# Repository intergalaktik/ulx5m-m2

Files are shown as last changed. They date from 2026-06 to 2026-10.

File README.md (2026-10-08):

# Work in progress!!! 

# Please check the list of confirmed working

# ULX5M-GS
GateMate FPGA on M2 card

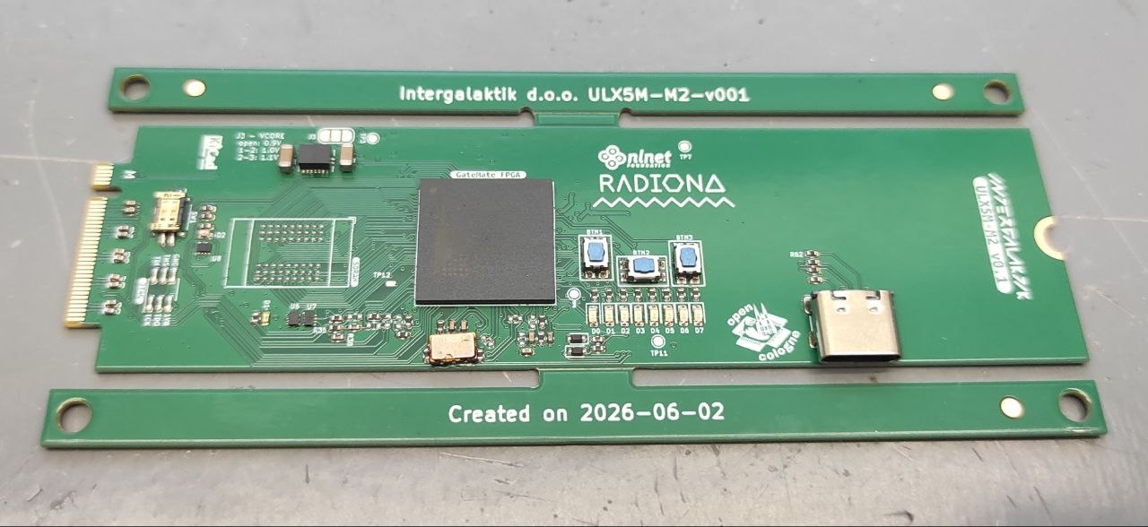
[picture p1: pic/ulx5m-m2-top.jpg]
TOP

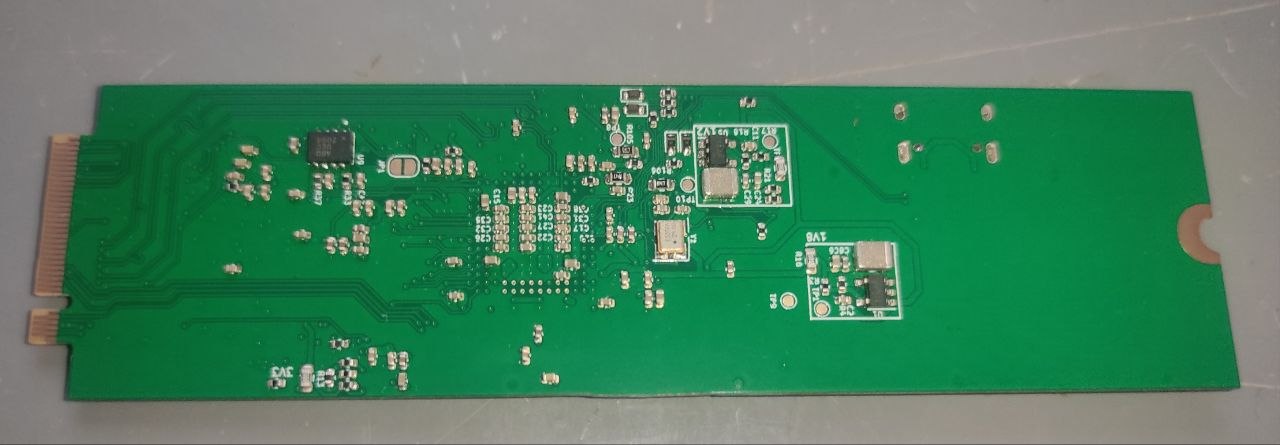
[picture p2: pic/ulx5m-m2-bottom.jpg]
BOTTOM


## Blinky

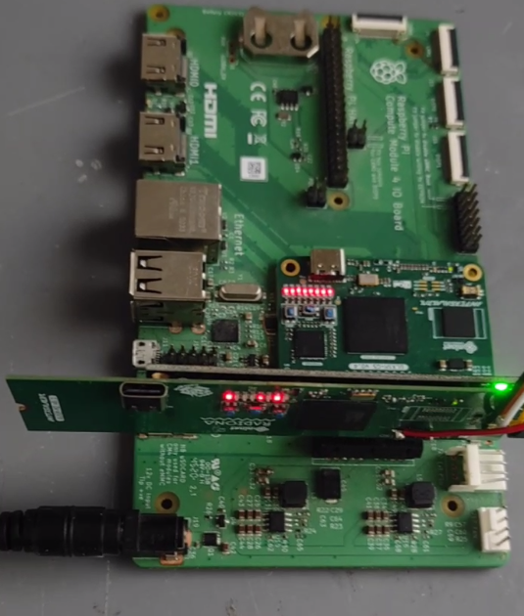
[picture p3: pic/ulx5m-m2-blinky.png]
Blinky video


#### ULX5M-M2 V001

- [x] JTAG 
- [x] FLASH
- [x] LEDs
- [x] Blinkey
- [x] USB - device shows up
- [] BTNS
- [] SDRAM
- [x] SerDes with connection to ULX5M-GS - low speed 1.25Gbit/s SerDes transfer.
- [] PCIe

#### ULX5M-M2 V002 - ready for order

- [] JTAG 
- [] FLASH
- [] LEDs
- [] Blinkey
- [] USB - device shows up
- [] BTNS
- [] SDRAM
- [] SerDes with connection to ULX5M-GS I am getting low speed SerDes transfer.
- [] PCIe

## References

https://github.com/intergalaktik/ulx5m-gs

https://github.com/OLIMEX/GateMateA1-EVB

https://github.com/intergalaktik/Extension_Boards_for_Olimex_GateMate

https://github.com/YosysHQ/prjpeppercorn-test-cases

https://github.com/YosysHQ/prjpeppercorn
  
https://github.com/chili-chips-ba/openCologne

https://www.chili-chips.xyz/open-cologne

## Acknowledgements

This project was done in collaboration with Chili Chips*Ba team. 
They have put enormes effort in making all cores to work on GateMate even before we have our own board!
Thanks to them now we have big set of cores that can be used to check and improve opensource toolchain!
They are proven to be reliable partners that solves problem quickly and on side works on educating younger generations!
Also big thanks goes to YosysHQ as they are doing miracles with open source tooling, and we now finaly have one that works for GateMate!
From YosysHQ special thanks to Micko and Lofty that are helping in real time on Discord!
Special thanks to Patrick from Cologne, as without him and rest of Cologne team we would not be able to get this project done.

## Work on this board is financed by NLnet foundation

NLnet

https://nlnet.nl/project/openCologne/

https://nlnet.nl/project/OpenCologne-PCIe/

https://github.com/chili-chips-ba/openCologne-PCIE

This project was funded through the NGI0 Commons Fund, a fund established by NLnet with financial support from the European Commission's Next Generation Internet programme, under the aegis of DG Communications Networks, Content and Technology under grant agreement No 101135429. Additional funding is made available by the Swiss State Secretariat for Education, Research and Innovation (SERI).

## Check up our blogposts
Comming soon!!!

## Contact us

Discord: https://discord.gg/qwMUk6W

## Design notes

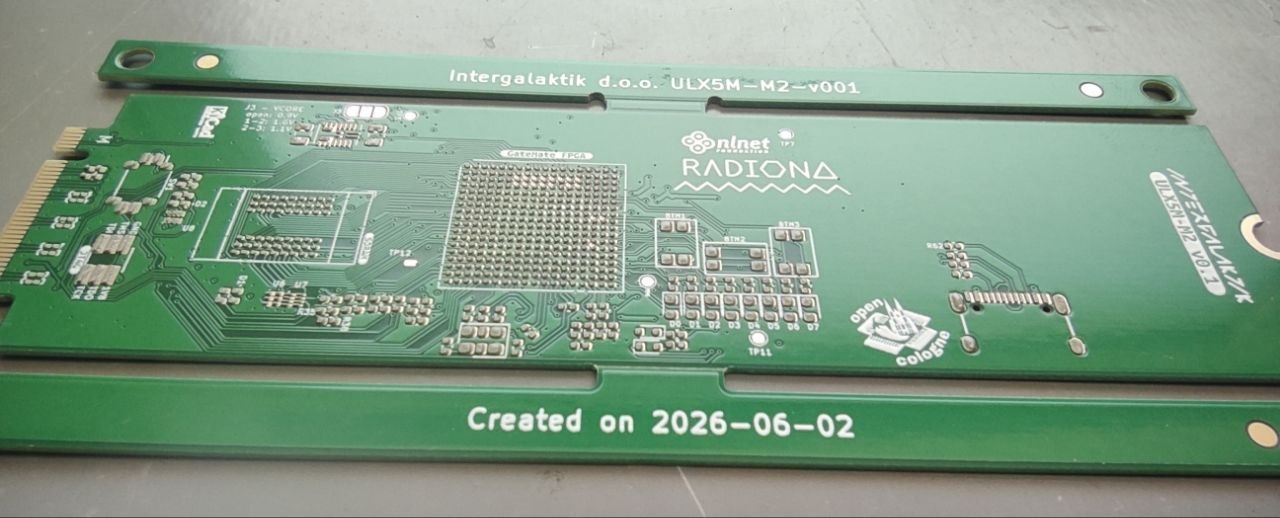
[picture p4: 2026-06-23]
pic/ulx5m-m2-top-paste.jpg

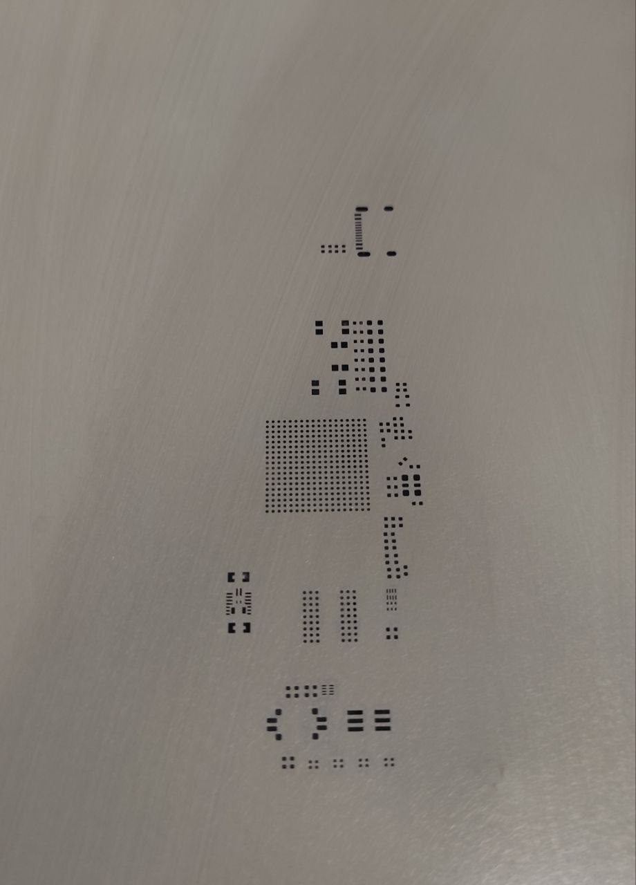
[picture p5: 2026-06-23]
pic/ulx5m-m2-top-stencill.jpg

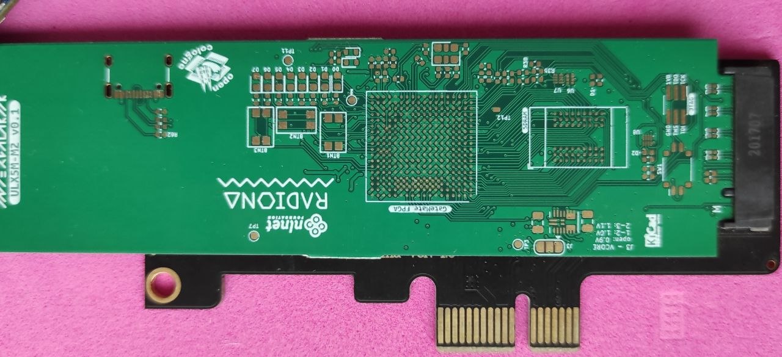
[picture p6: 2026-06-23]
pic/ulx5m-m2-top-PCIe.jpg

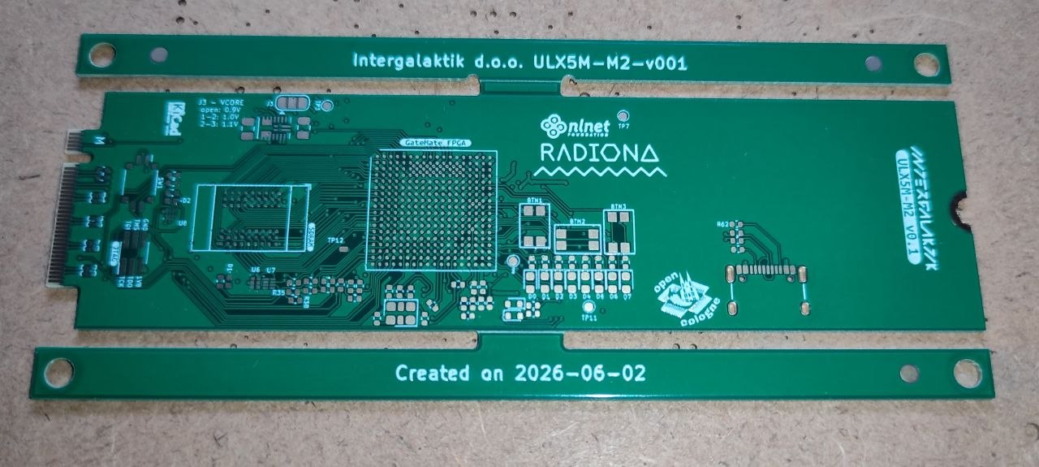
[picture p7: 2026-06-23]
pic/ulx5m-m2-top-PCB.jpg

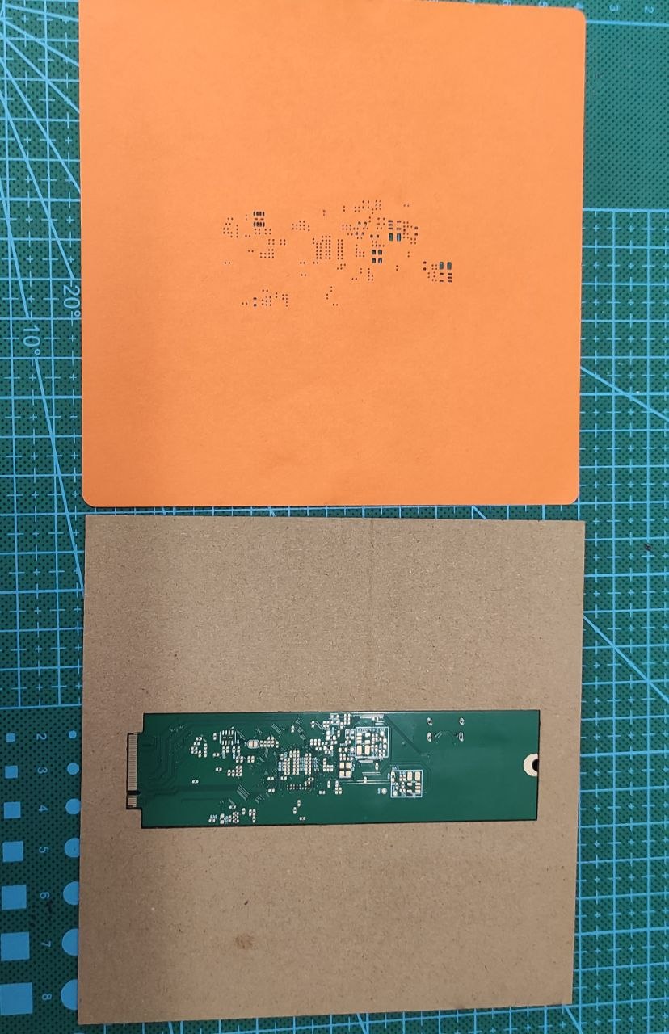
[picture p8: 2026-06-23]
pic/ulx5m-m2-bottom-stencill.jpg

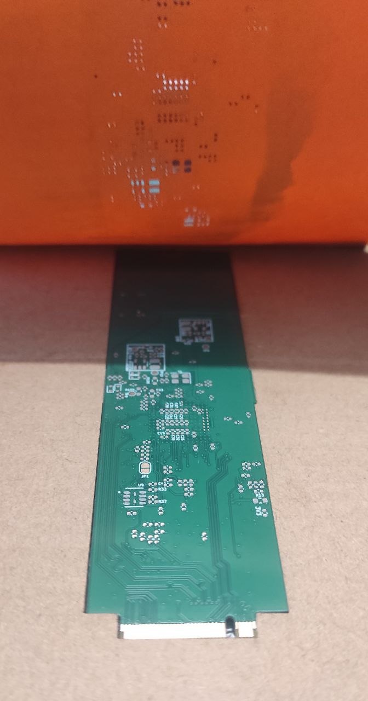
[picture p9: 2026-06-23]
pic/ulx5m-m2-bottom-stencill-paste.jpg

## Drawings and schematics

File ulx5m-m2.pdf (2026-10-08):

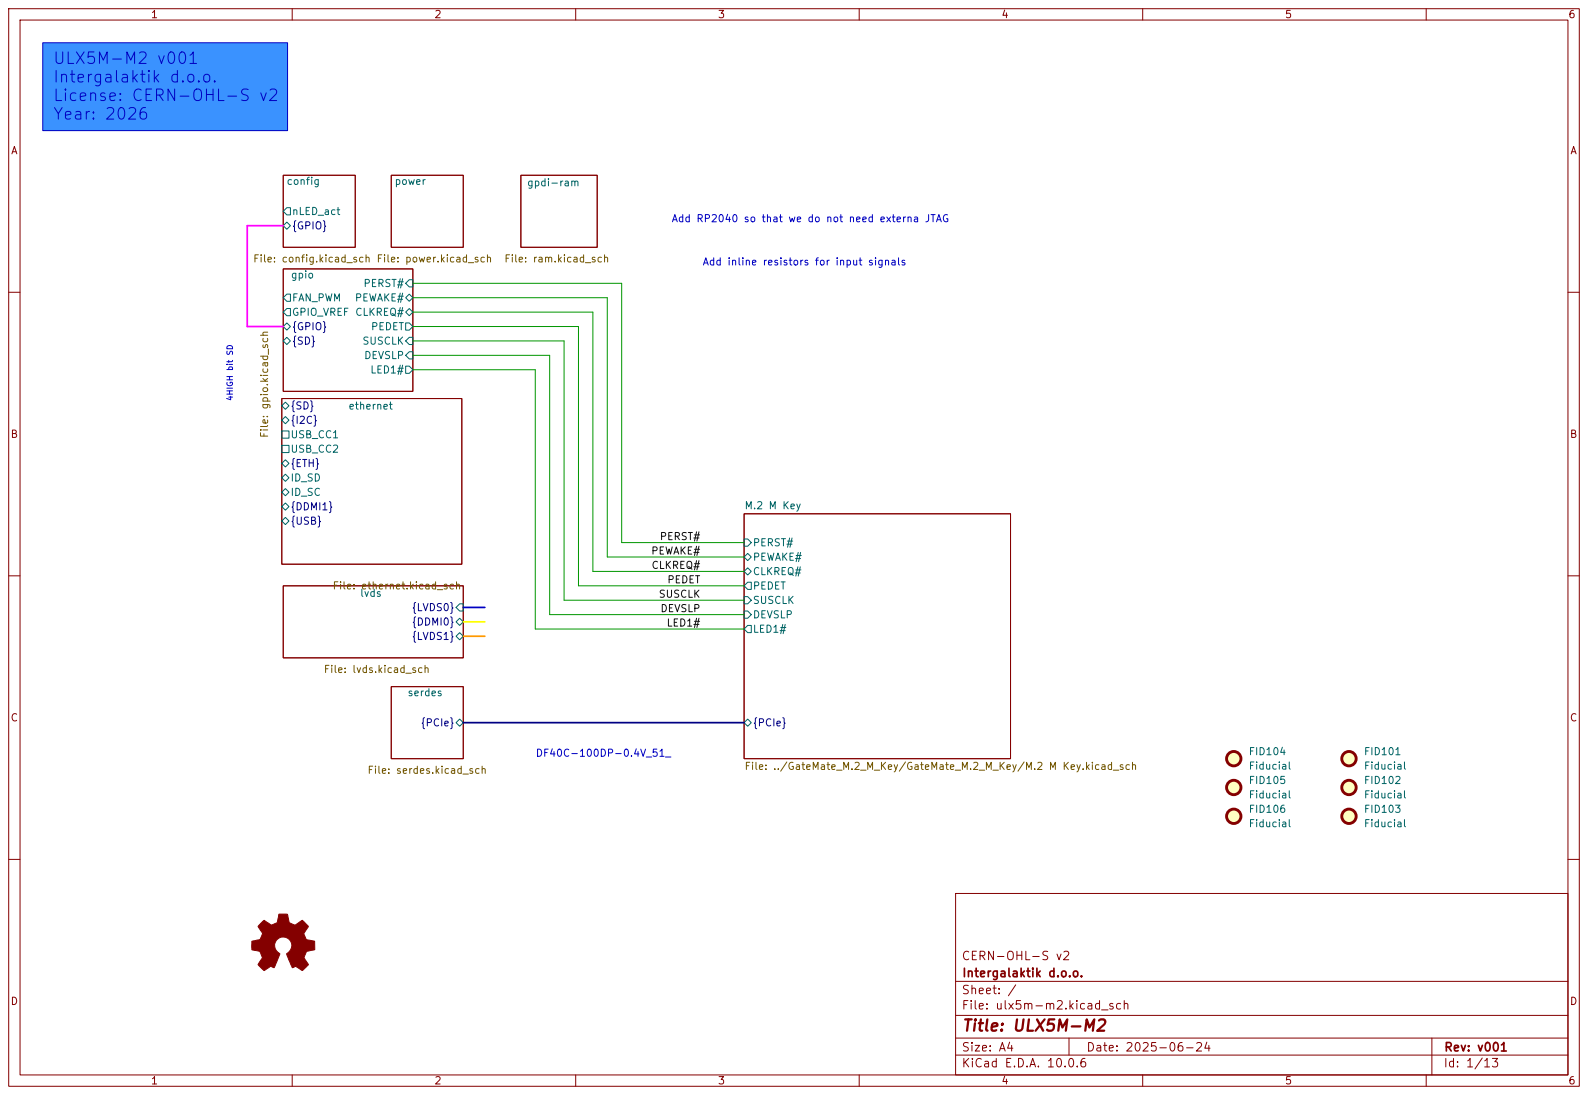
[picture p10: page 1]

Add RP2040 so that we do not need externa JTAG Add inline resistors for input signals 4HIGH bit SD

{PCIe} M.2 M Key File: ../GateMate_M.2_M_Key/GateMate_M.2_M_Key/M.2 M Key.kicad_sch

{PCIe} serdes File: serdes.kicad_sch

Size: A4 | Rev: v001
KiCad E.D.A. 10.0.6 | Id: 1/13

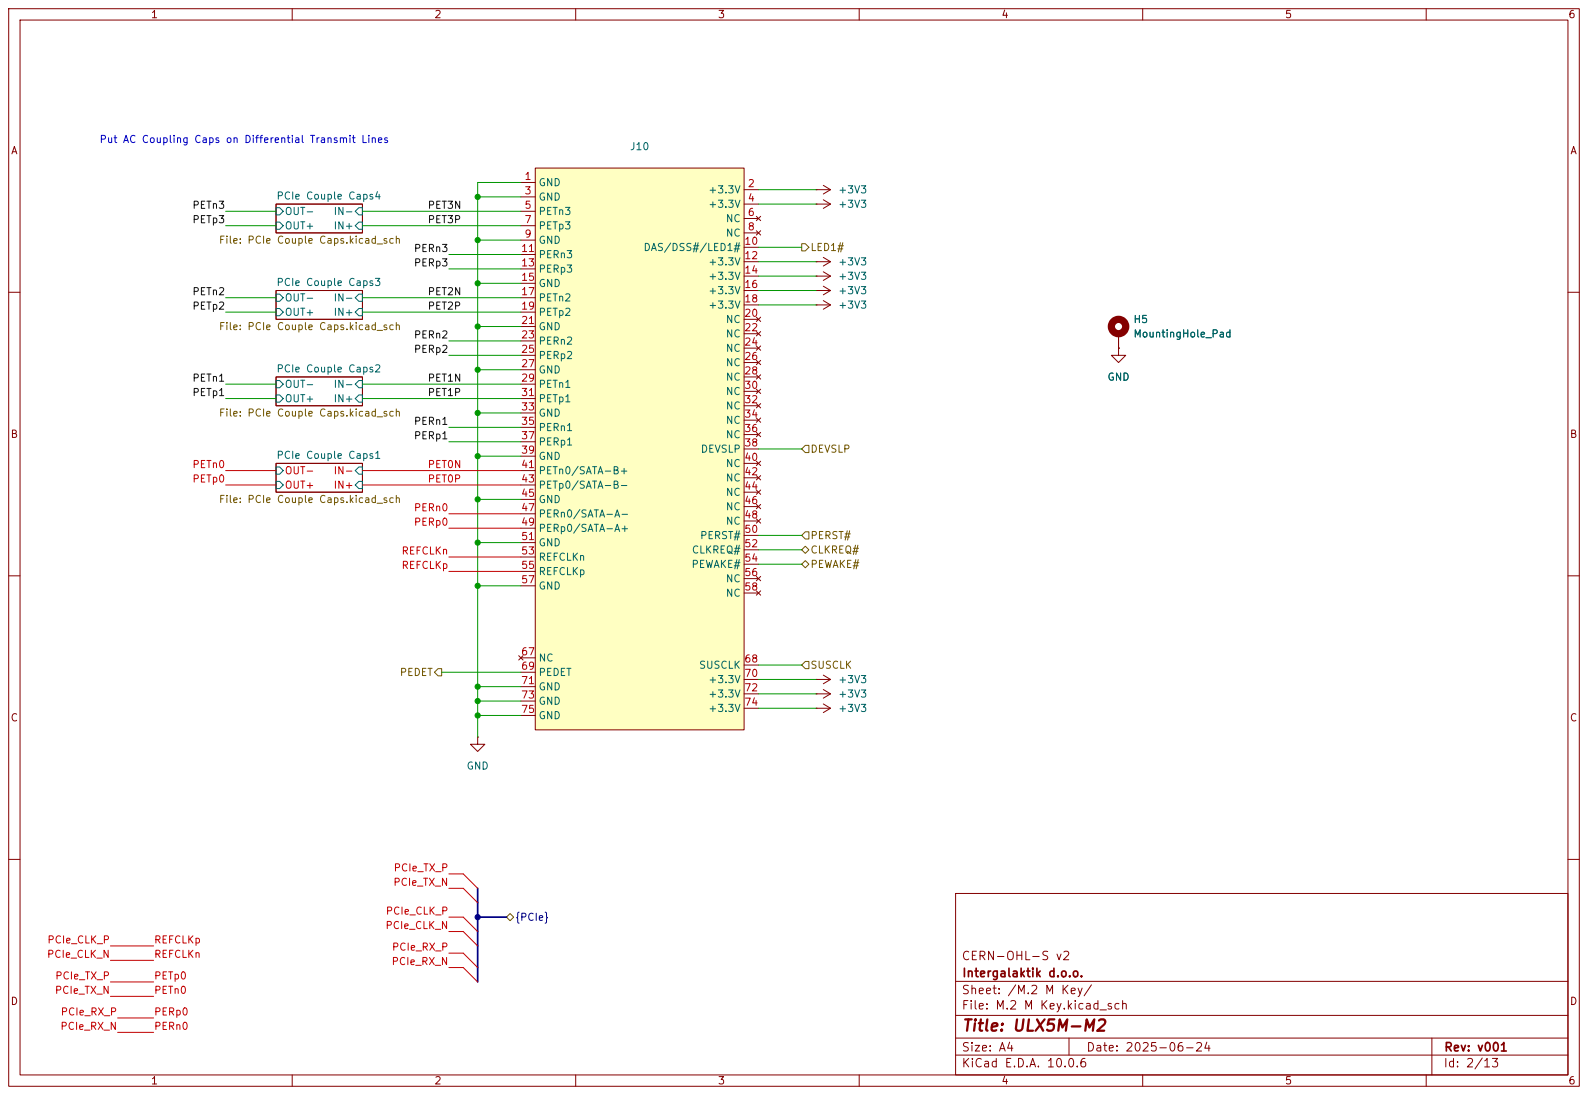
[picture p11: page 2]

File: PCIe Couple Caps.kicad_sch OUT-

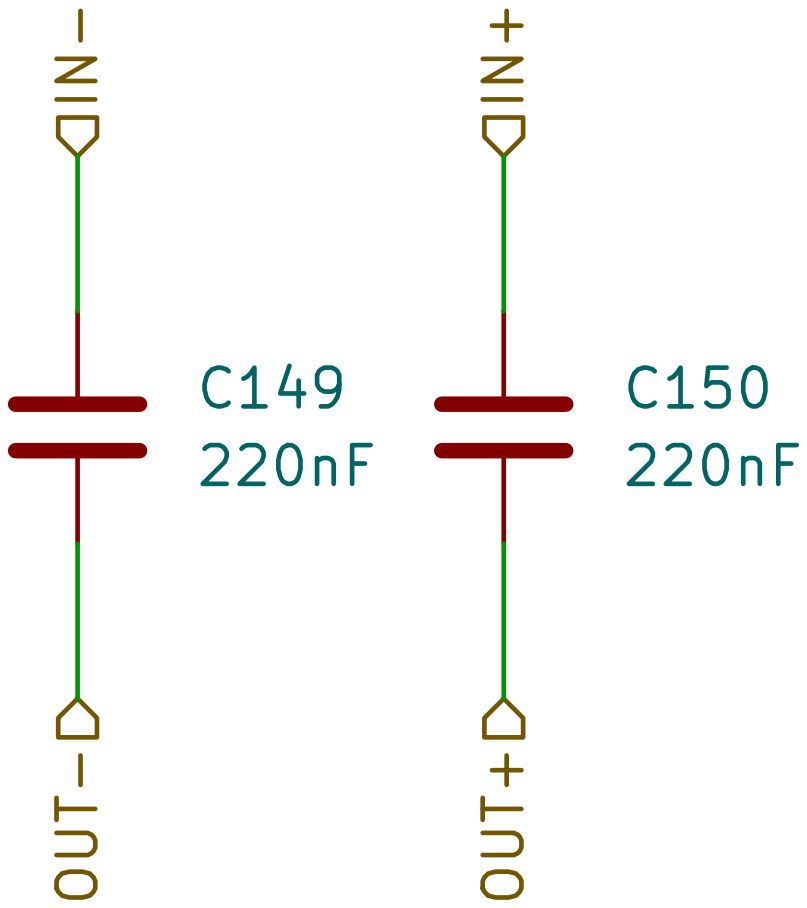
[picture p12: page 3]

CERN-OHL-S v2
Intergalaktik d.o.o.
Sheet: /M.2 M Key/PCIe Couple Caps4/
File: PCIe Couple Caps.kicad_sch
Title: ULX5M-M2

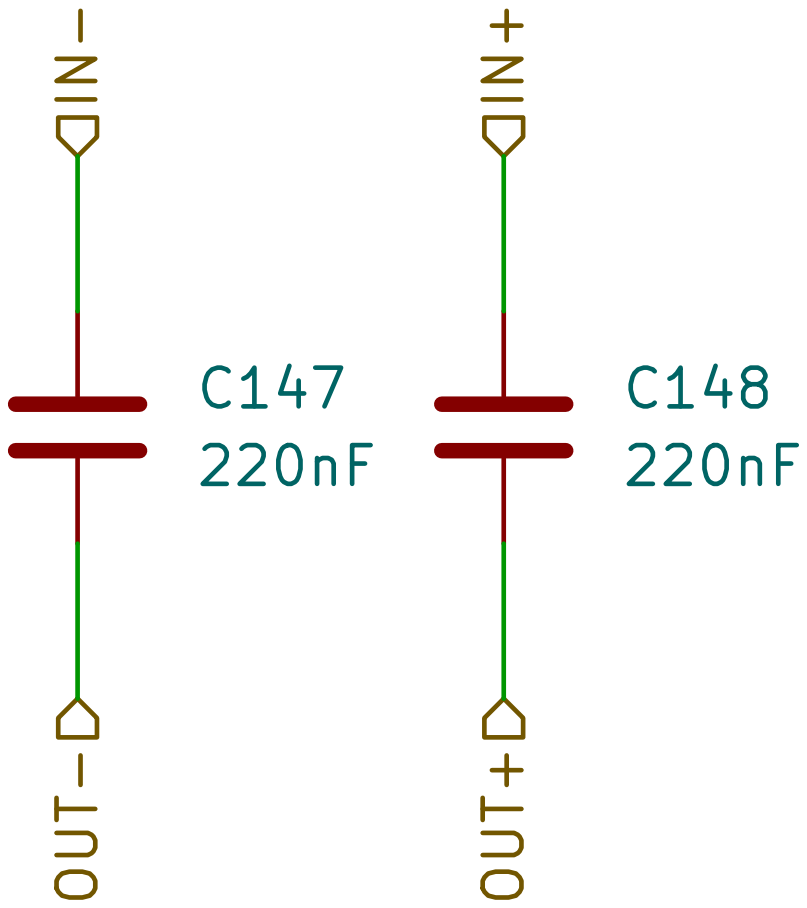
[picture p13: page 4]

CERN-OHL-S v2
Intergalaktik d.o.o.
Sheet: /M.2 M Key/PCIe Couple Caps3/
File: PCIe Couple Caps.kicad_sch
Title: ULX5M-M2

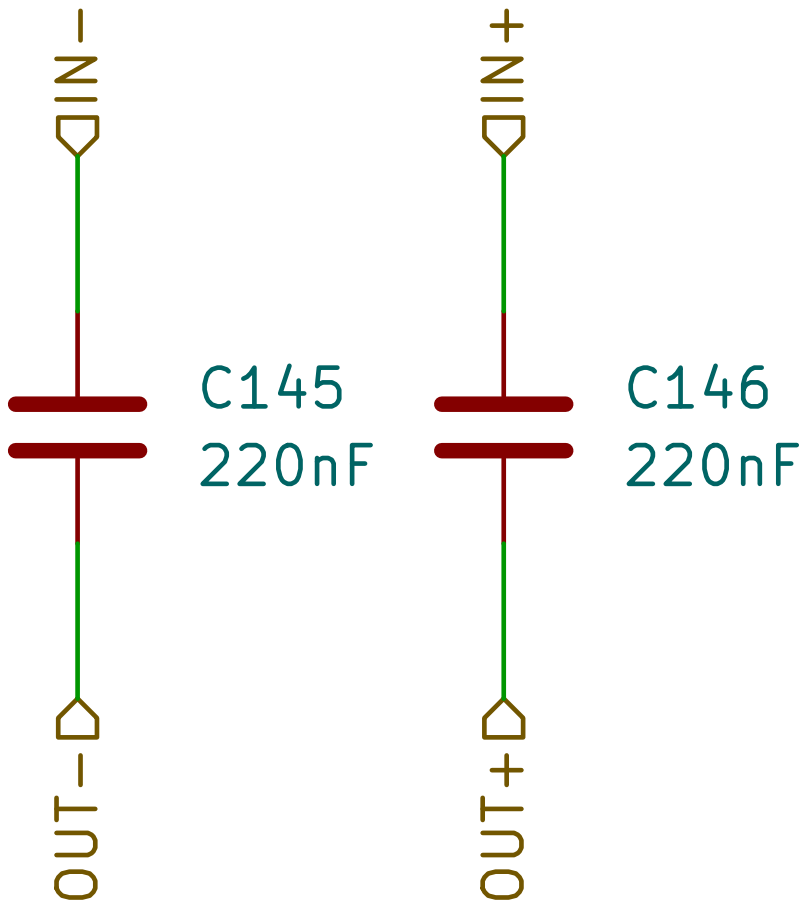
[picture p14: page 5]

CERN-OHL-S v2
Intergalaktik d.o.o.
Sheet: /M.2 M Key/PCIe Couple Caps2/
File: PCIe Couple Caps.kicad_sch
Title: ULX5M-M2

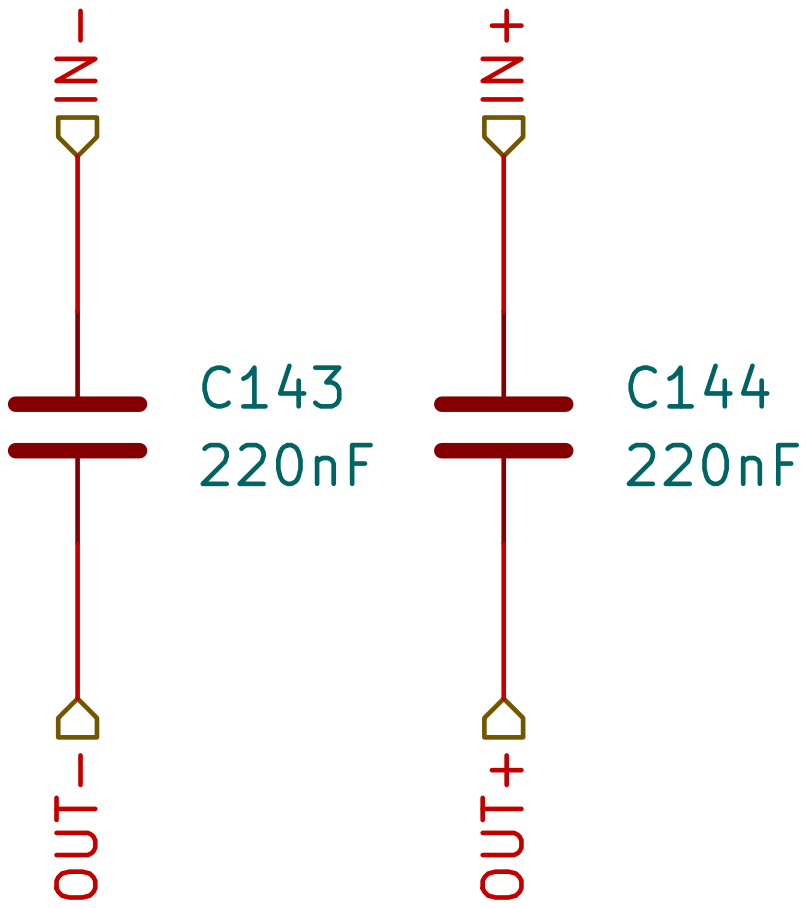
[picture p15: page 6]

CERN-OHL-S v2
Intergalaktik d.o.o.
Sheet: /M.2 M Key/PCIe Couple Caps1/
File: PCIe Couple Caps.kicad_sch
Title: ULX5M-M2

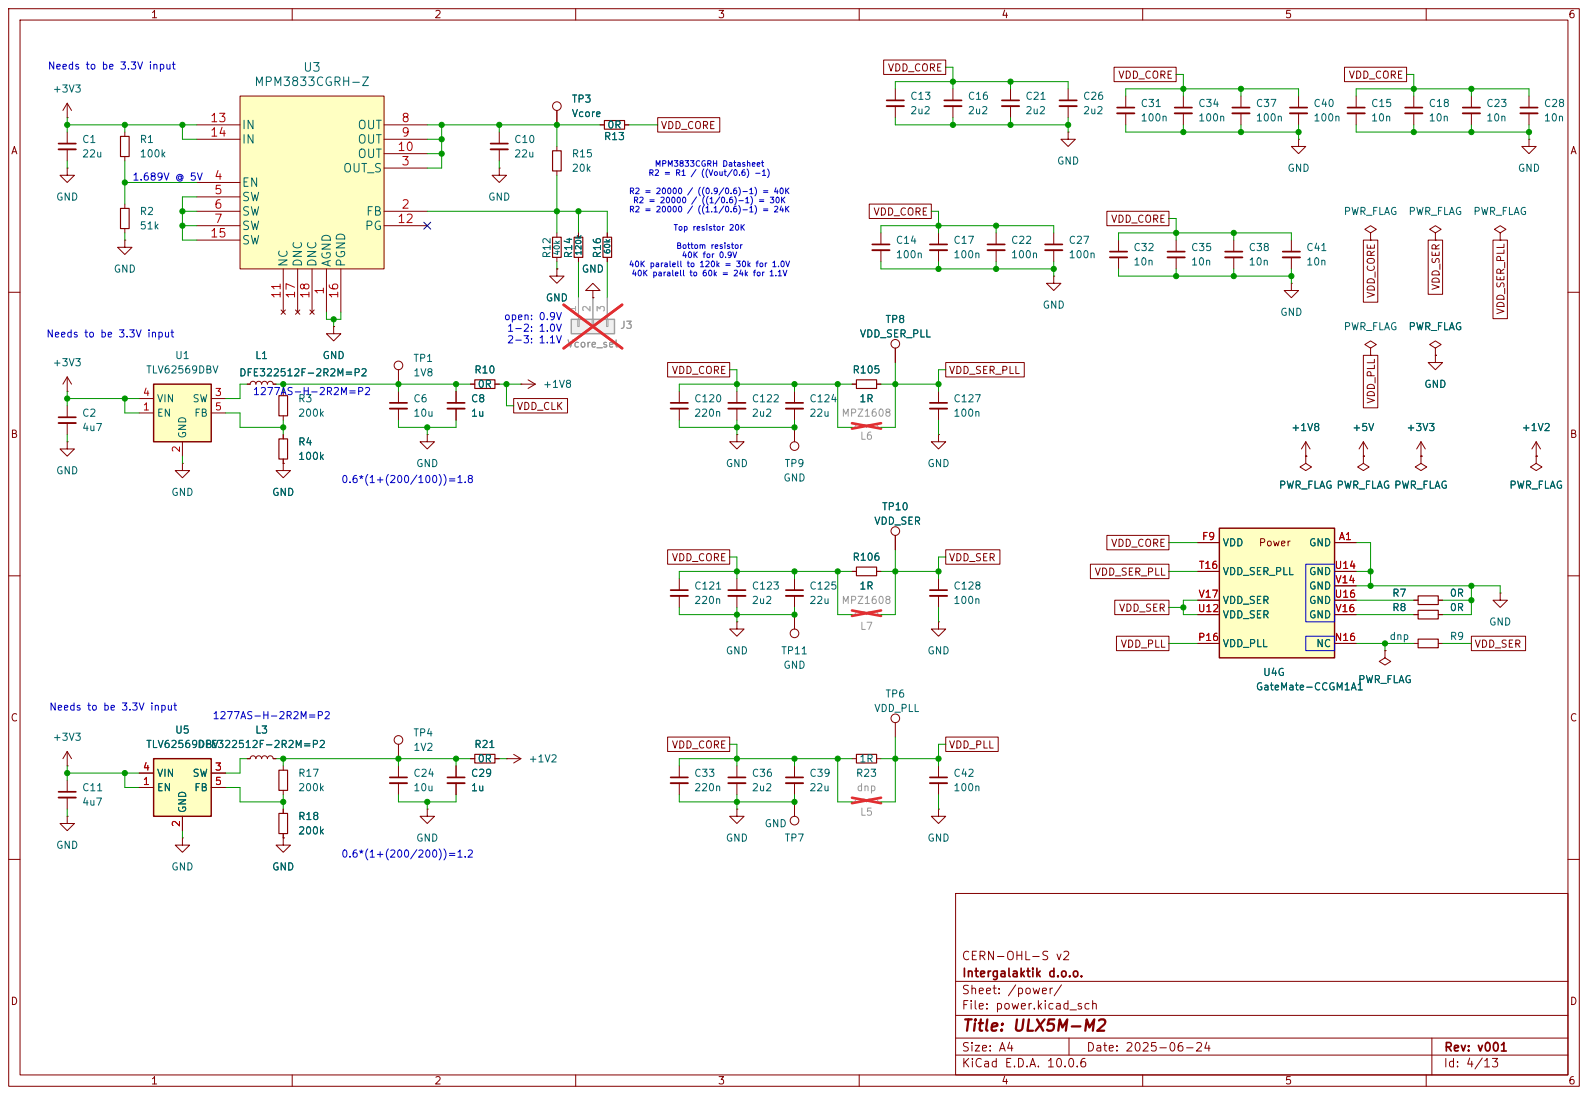
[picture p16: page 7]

Bottom resistor 40K for 0.9V 40K paralell to 120k = 30k for 1.0V 40K paralell to 60k = 24k for 1.1V 1277AS-H-2R2M=P2

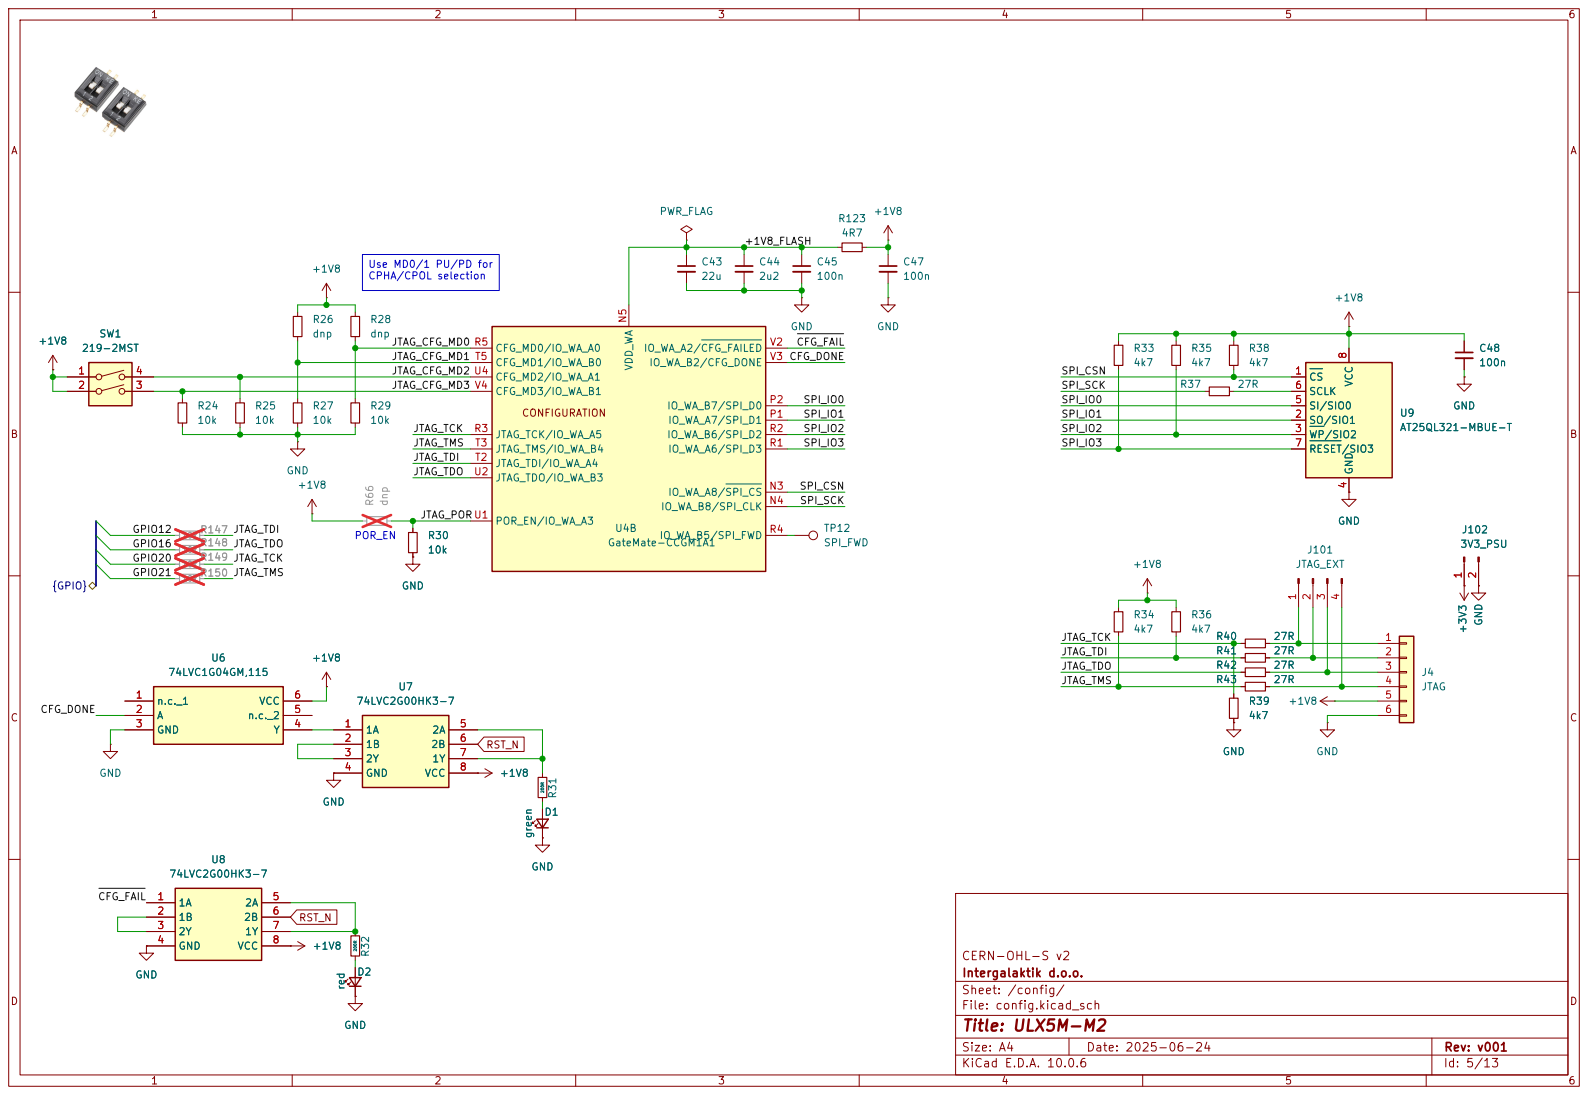
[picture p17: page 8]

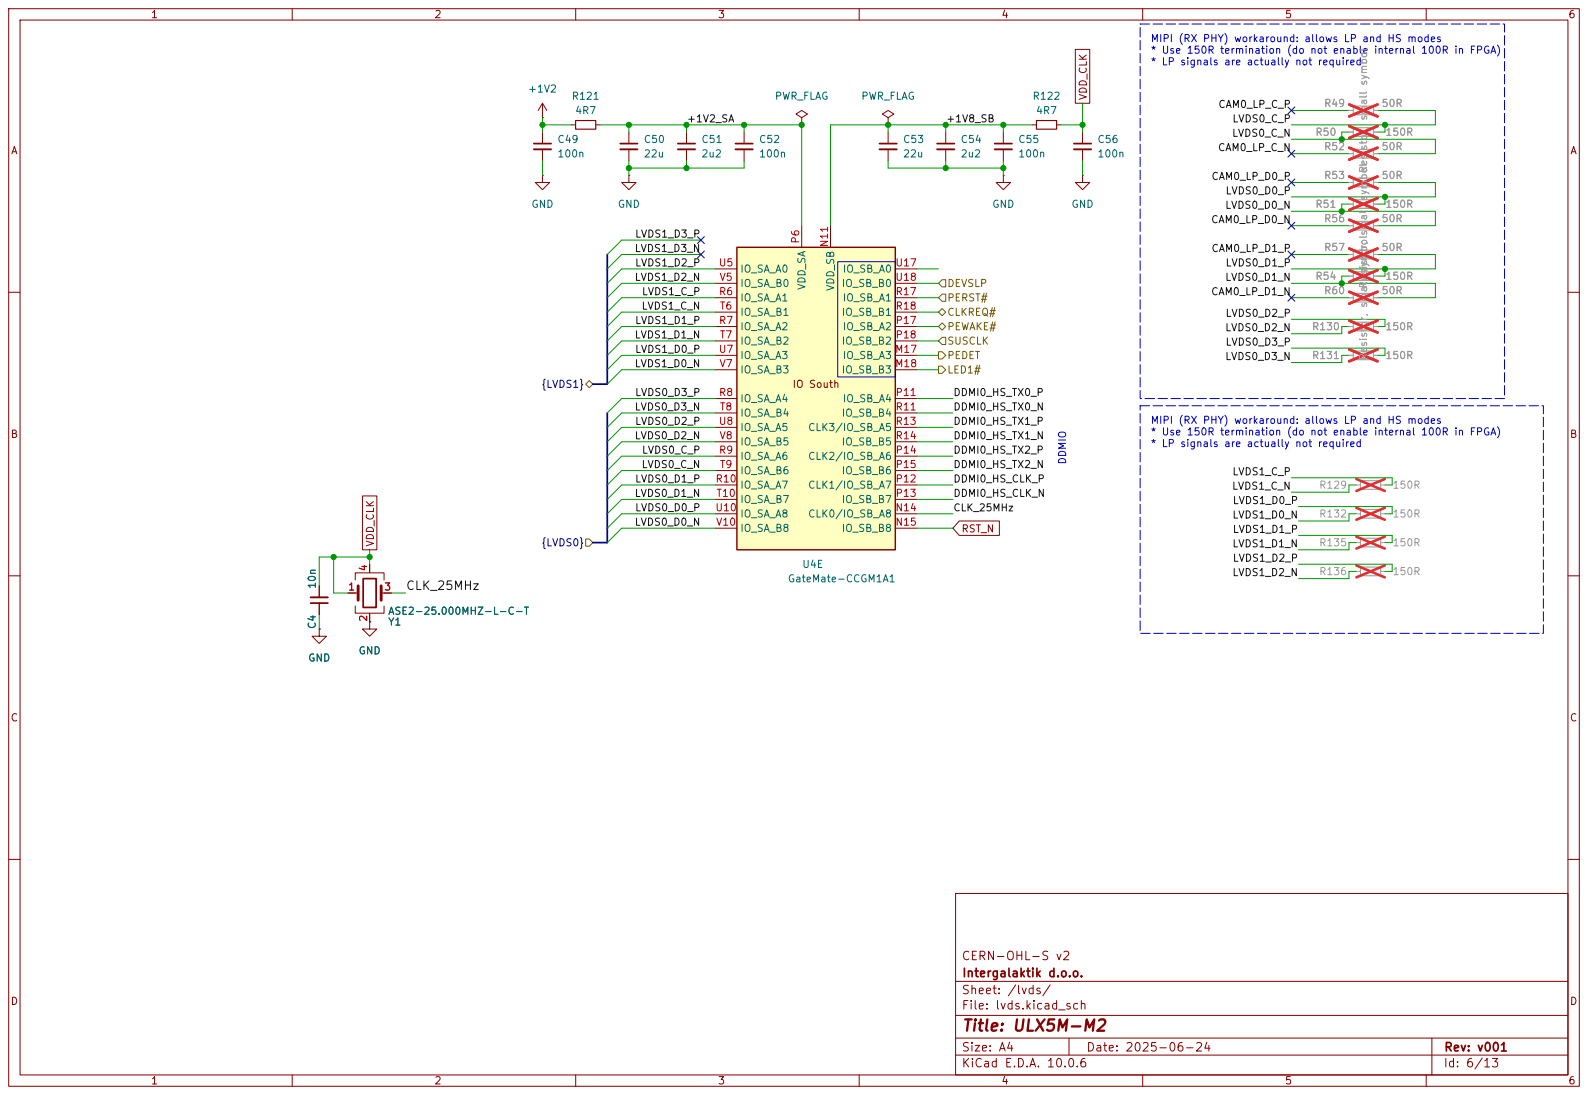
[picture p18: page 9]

* Use 150R termination (do not enable internal 100R in FPGA) * LP signals are actually not required

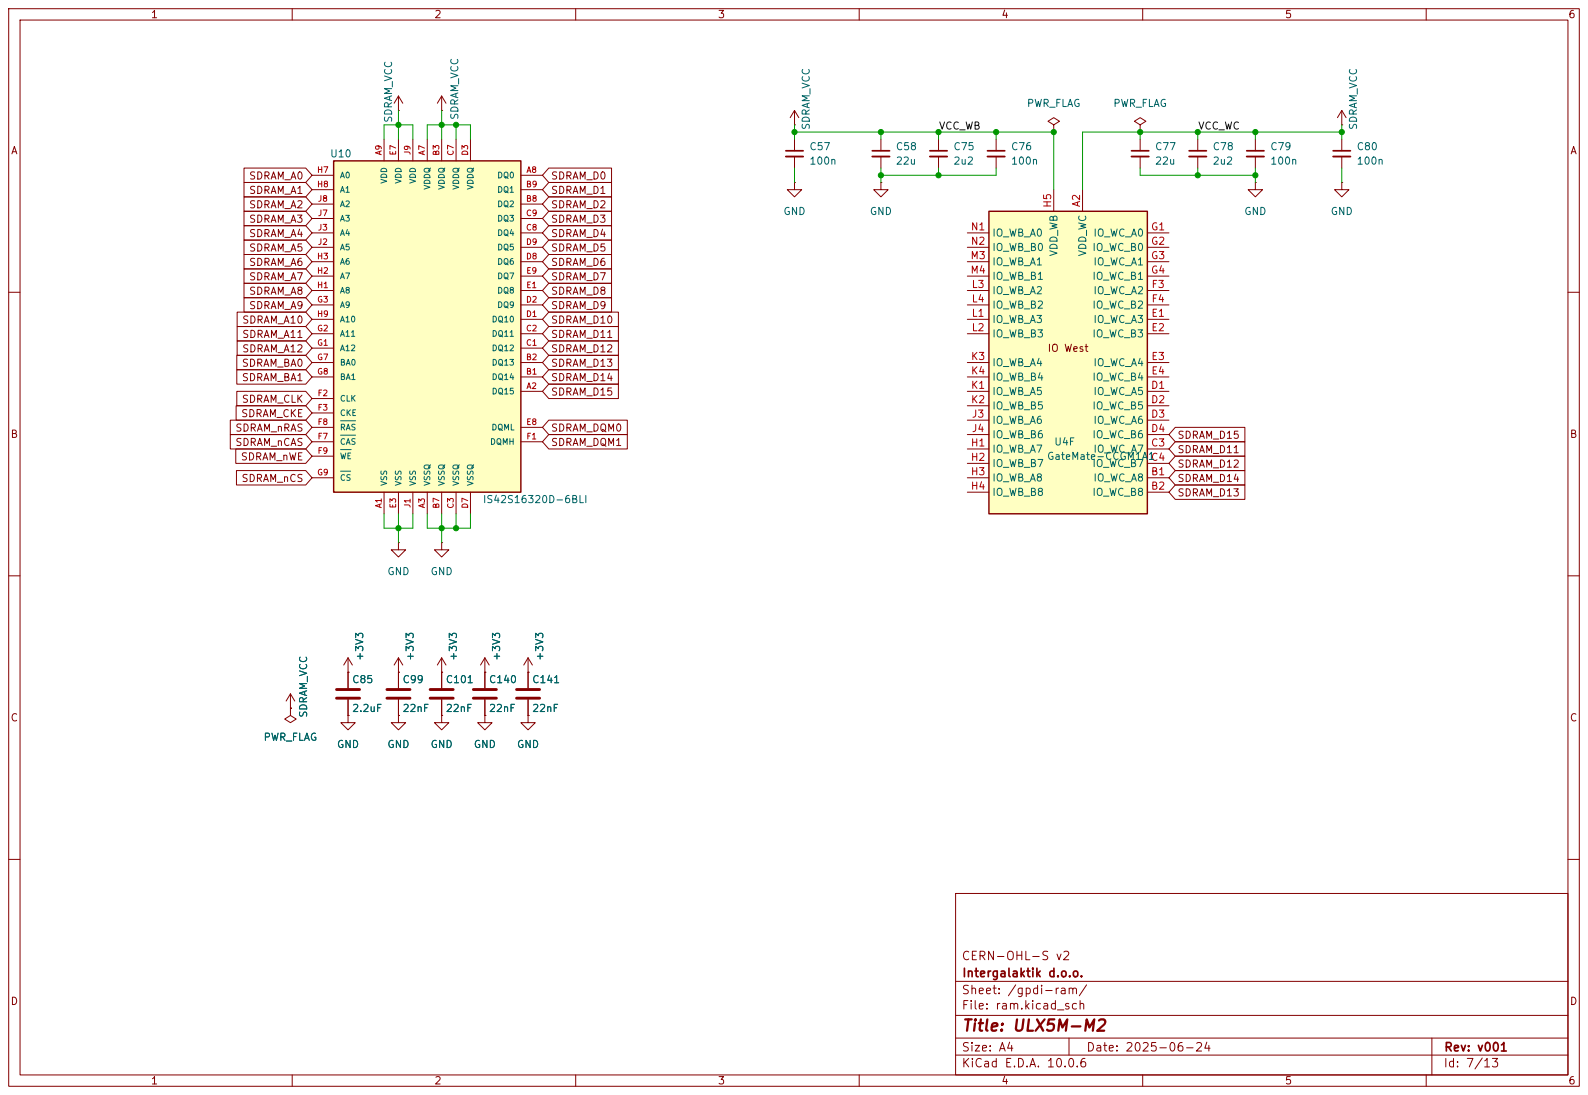
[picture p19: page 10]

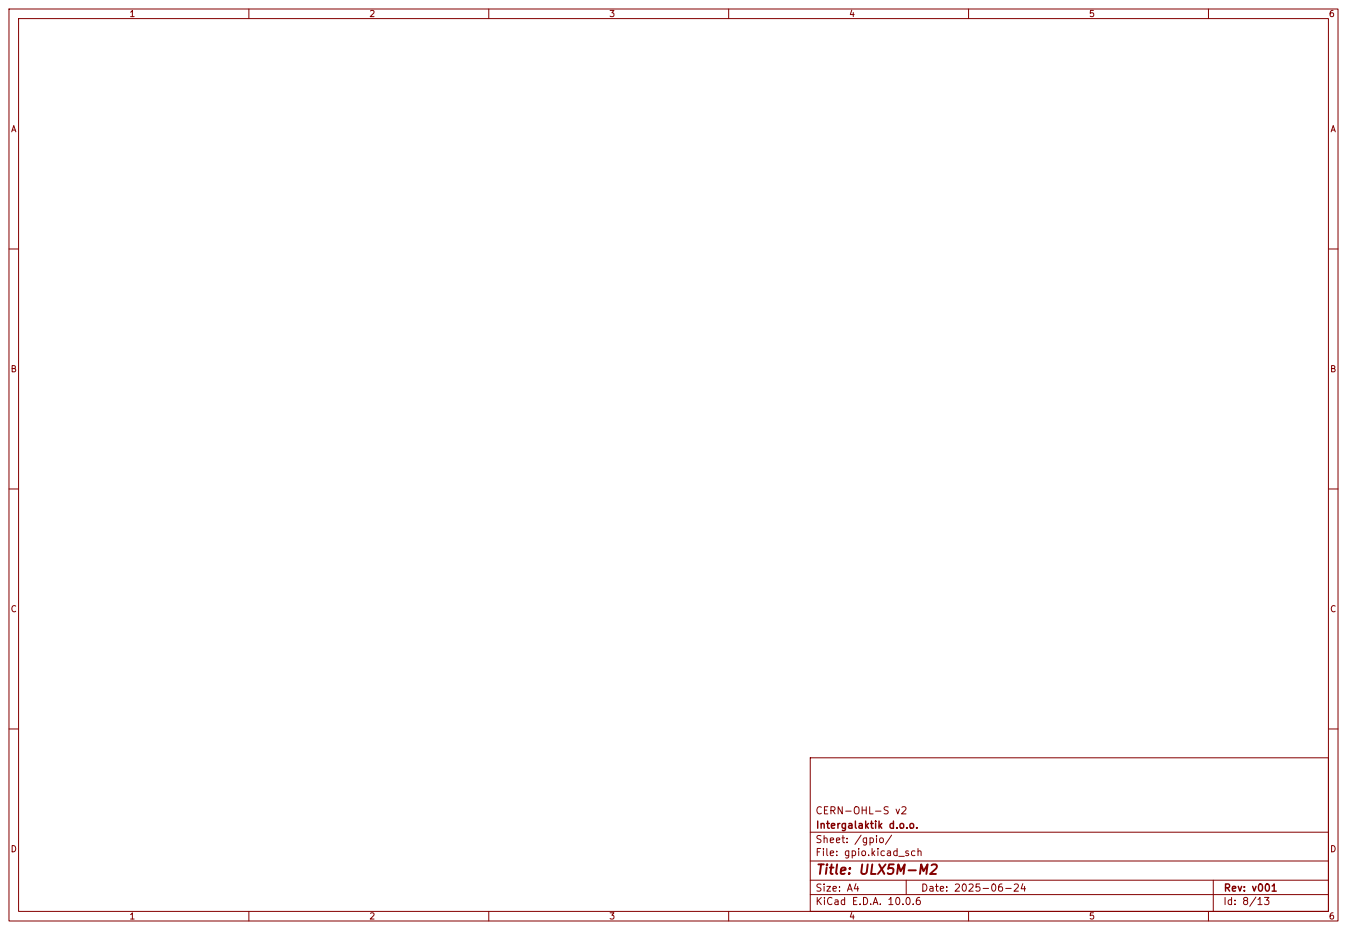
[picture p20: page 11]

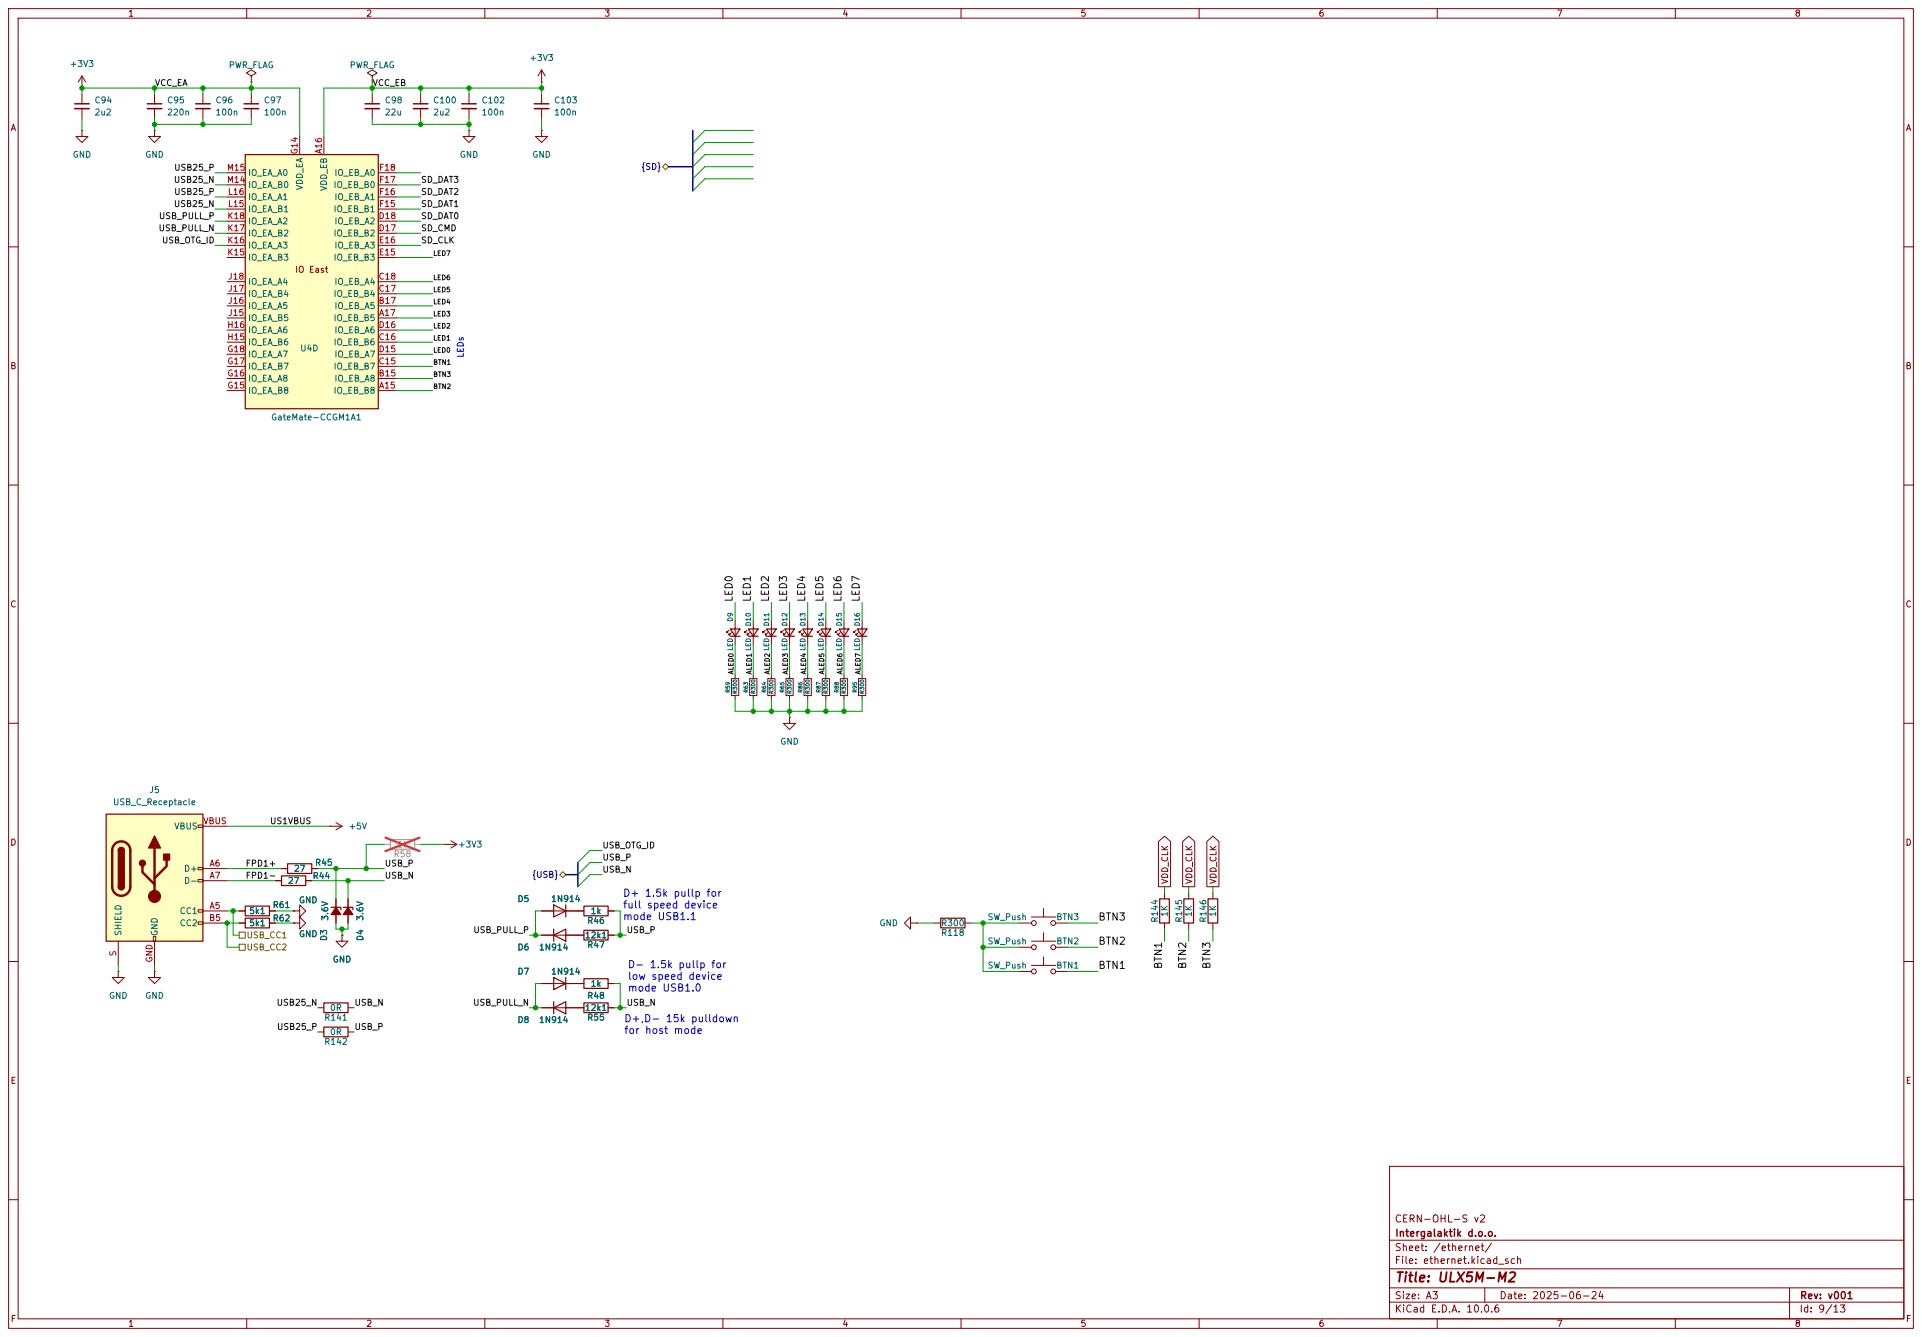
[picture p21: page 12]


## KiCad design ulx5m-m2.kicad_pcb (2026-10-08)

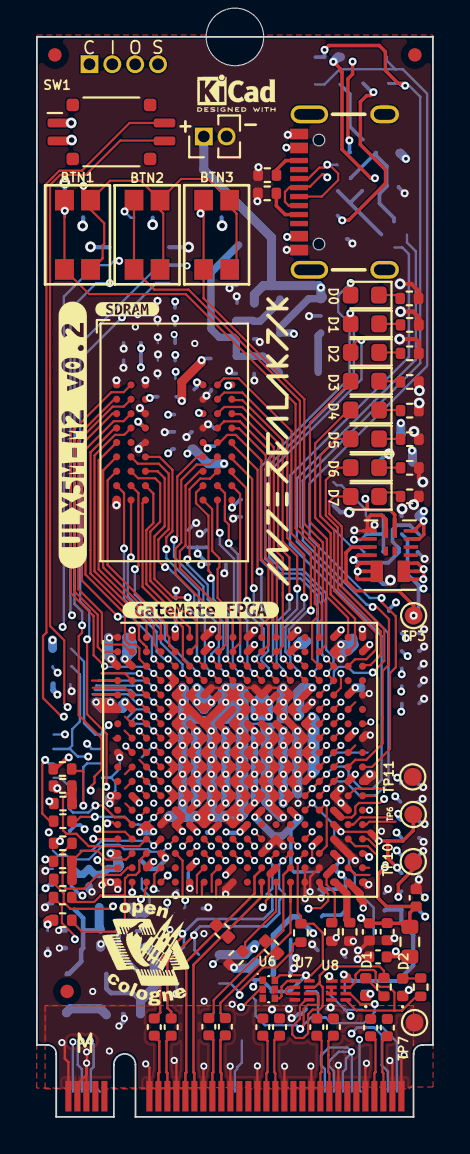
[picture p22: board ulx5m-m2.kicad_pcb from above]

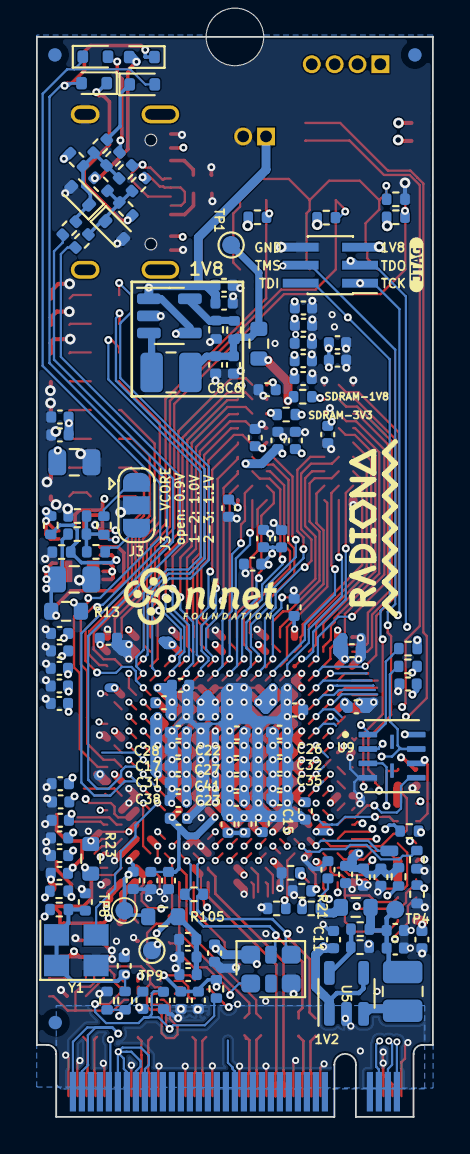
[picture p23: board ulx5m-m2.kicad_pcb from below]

Board: 6 copper layers, 22.0 x 60.0 mm, 234 parts (155 on the bottom side), 151 nets.

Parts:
BTN1, BTN2, BTN3: SW_Push; Switch_EVPAA
C1, C10: 22u; C_0805_2012Metric
C2, C11: 4u7; C_0402_1005Metric
C4, C15, C18, C23, C28, C32, C35, C38, C41, C126: 10n; C_0402_1005Metric
C6, C24: 10u; C_0402_1005Metric
C8, C29: 1u; C_0402_1005Metric
C13, C16, C21, C26, C36, C44, C51, C54, C75, C78, C86, C90, C94, C100, C122, C123, C131: 2u2; C_0402_1005Metric
C14, C17, C22, C27, C31, C34, C37, C40, C42, C45, C47, C48, C49, C52, C55, C56, C57, C76, C79, C80, C88, C89, C92, C93, C96, C97, C102, C103, C127, C128, C132, C133, C136, C137, C138: 100n; C_0402_1005Metric
C33, C87, C91, C95, C120, C121: 220n; C_0402_1005Metric
C39, C43, C50, C53, C58, C77, C98, C124, C125: 22u; C_0402_1005Metric
C85: 2.2uF; C_0402_1005Metric
C99, C101, C140, C141: 22nF; C_0402_1005Metric
C143, C144, C145, C146, C147, C148, C149, C150: 220nF; C_0402_1005Metric
D1: green; D_0402_1005Metric
D2: red; D_0402_1005Metric
D3, D4: 3.6V; D_SOD-523
D5, D6, D7, D8: 1N914; D_SOD-523
D9, D10, D11, D12, D13, D14, D15, D16: LED; LED_0603_1608Metric
FID101, FID102, FID103, FID104, FID105, FID106: Fiducial; Fiducial_0.75mm_Mask1.5mm
H5: MountingHole_Pad; MountingHole_3.2mm_M3
J3: Vcore_sel; SolderJumper-3_P1.3mm_Open_RoundedPad1.0x1.5mm
J4: JTAG; PinHeader_2x03_P1.00mm_Vertical_SMD
J5: USB_C_Receptacle; USB-C_16
J10: M.2 M Key Connector
J101: JTAG_EXT; PinHeader_1x04_P1.27mm_Vertical
J102: 3V3_PSU; PinHeader_1x02_P1.27mm_Vertical
L1, L3: DFE322512F-2R2M=P2; L_1008_2520Metric
LoGo_opencologne: MountingHole; open_cologne_small
R1, R4, R143: 100k; R_0402_1005Metric
R2: 51k; R_0402_1005Metric
R3, R17, R18: 200k; R_0402_1005Metric
R7, R8, R116, R141, R142: 0R; R_0402_1005Metric
R9, R66, R107, R108, R110, R112, R113, R115: dnp; R_0402_1005Metric
R10, R13, R21: 0R; R_0603_1608Metric
R12: 40k; R_0402_1005Metric
R14: 120k; R_0402_1005Metric
R15: 20k; R_0402_1005Metric
R16: 60k; R_0402_1005Metric
R23, R105, R106: 1R; R_0603_1608Metric
R24, R25, R27, R29, R30, R111: 10k; R_0402_1005Metric
R31, R32: 200R; R_0402_1005Metric
R33, R34, R35, R36, R38, R39: 4k7; R_0402_1005Metric
R37, R40, R41, R42, R43: 27R; R_0402_1005Metric
R44, R45: 27; R_0402_1005Metric
R46, R48, R58: 1k; R_0402_1005Metric
R47, R55: 12k1; R_0402_1005Metric
R59, R63, R64, R65, R86, R87, R88, R95, R118: R300; R_0402_1005Metric
R61, R62: 5k1; R_0402_1005Metric
R109: 200; R_0402_1005Metric
R121, R122, R123: 4R7; R_0402_1005Metric
R144, R145, R146: 1K; R_0402_1005Metric
SW1: 219-2MST; SW_DIP_SPSTx02_Slide_Copal_CVS-02xB_W5.9mm_P1mm
TP1: 1V8; TestPoint_Pad_D1.0mm
TP3: Vcore; TestPoint_Pad_D1.0mm
TP4: 1V2; TestPoint_Pad_D1.0mm
TP6: VDD_PLL; TestPoint_Pad_D1.0mm
TP7, TP9, TP11: GND; TestPoint_Pad_D1.0mm
TP8: VDD_SER_PLL; TestPoint_Pad_D1.0mm
TP10: VDD_SER; TestPoint_Pad_D1.0mm
TP12: SPI_FWD; TestPoint_Pad_1.0x1.0mm
U1, U5: TLV62569DBV; SOT-23-5
U3: MPM3833CGRH-Z
U4: GateMate-CCGM1A1; BGA-324_15.0x15.0mm_Layout18x18_P0.8mm_Ball0.45mm_Pad0.4mm_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
U6: 74LVC1G04GM,115; PESD3V3L5UF115
U7, U8: 74LVC2G00HK3-7; 74LVC2G00HK37
U9: AT25QL321-MBUE-T; SON80P400X300X60-10N
U10: IS42S16320D-6BLI
X2: 511FCA100M000BAG; Oscillator_SMD_SiTime_PQFD-6L_3.2x2.5mm
Y1: ASE2-25.000MHZ-L-C-T; Crystal_SMD_TXC_7M-4Pin_3.2x2.5mm
kibuzzard-6A9AE930: G***; kibuzzard-6A9AE930
kibuzzard-686AA7AF: G***; kibuzzard-686AA7AF
kibuzzard-686AA726: G***; kibuzzard-686AA726
kibuzzard-686CE423: G***; kibuzzard-686CE423
radiona: radiona

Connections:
+1V2: C49.1, R21.2, R121.1
+3V3: C1.1, C2.1, C11.1, C85.1, C94.1, C95.1, C96.1, C97.1, C98.1, C99.1, C100.1, C101.1, C102.1, C103.1, C140.1, C141.1, J10.2 (+3.3V), J10.4 (+3.3V), J10.12 (+3.3V), J10.14 (+3.3V), J10.16 (+3.3V), J10.18 (+3.3V), J10.70 (+3.3V), J10.72 (+3.3V), J10.74 (+3.3V), J102.1, R1.1, R58.2, R115.2, U1.1 (EN), U1.4 (VIN), U3.13 (IN), U3.14 (IN), U4.A16 (VDD_EB), U4.B18 (VDD_EB), U4.E14 (VDD_EB), U4.E17 (VDD_EB), U4.F13 (VDD_EB), U4.G14 (VDD_EA), U4.H17 (VDD_EA), U4.J14 (VDD_EA), U4.L14 (VDD_EA), U4.L17 (VDD_EA), U5.1 (EN), U5.4 (VIN)
/M.2 M Key/PCIe_CLK_N: C137.2, J10.53 (REFCLKn)
/M.2 M Key/PCIe_CLK_P: C136.2, J10.55 (REFCLKp)
/M.2 M Key/PCIe_RX_N: J10.47 (PERn0/SATA-A-), R107.2, U4.V11 (SER_RX_N)
/M.2 M Key/PCIe_RX_P: J10.49 (PERp0/SATA-A+), R107.1, U4.U11 (SER_RX_P)
/M.2 M Key/PCIe_TX_N: C143.2, R110.2, U4.V13 (SER_TX_N)
/M.2 M Key/PCIe_TX_P: C144.2, R110.1, U4.U13 (SER_TX_P)
/M.2 M Key/PET0N: C143.1, J10.41 (PETn0/SATA-B+)
/M.2 M Key/PET0P: C144.1, J10.43 (PETp0/SATA-B-)
/M.2 M Key/PET1N: C145.1, J10.29 (PETn1)
/M.2 M Key/PET1P: C146.1, J10.31 (PETp1)
/M.2 M Key/PET2N: C147.1, J10.17 (PETn2)
/M.2 M Key/PET2P: C148.1, J10.19 (PETp2)
/M.2 M Key/PET3N: C149.1, J10.5 (PETn3)
/M.2 M Key/PET3P: C150.1, J10.7 (PETp3)
/config/+1V8_FLASH: C43.1, C44.1, C45.1, R123.1, U4.N5 (VDD_WA), U4.P3 (VDD_WA), U4.P5 (VDD_WA), U4.T1 (VDD_WA), U4.U3 (VDD_WA)
/config/CFG_DONE: U4.V3 (IO_WA_B2/CFG_DONE), U6.2 (A)
/config/JTAG_CFG_MD0: R29.1, U4.R5 (CFG_MD0/IO_WA_A0)
/config/JTAG_CFG_MD1: R27.1, U4.T5 (CFG_MD1/IO_WA_B0)
/config/JTAG_CFG_MD2: R25.1, SW1.4, U4.U4 (CFG_MD2/IO_WA_A1)
/config/JTAG_CFG_MD3: R24.1, SW1.3, U4.V4 (CFG_MD3/IO_WA_B1)
/config/JTAG_POR: R30.1, R66.2, U4.U1 (POR_EN/IO_WA_A3)
/config/JTAG_TCK: R39.1, R40.1, U4.R3 (JTAG_TCK/IO_WA_A5)
/config/JTAG_TDI: R36.2, R41.1, U4.T2 (JTAG_TDI/IO_WA_A4)
/config/JTAG_TDO: R42.1, U4.U2 (JTAG_TDO/IO_WA_B3)
/config/JTAG_TMS: R34.2, R43.1, U4.T3 (JTAG_TMS/IO_WA_B4)
/config/SPI_CSN: R38.2, U4.N3 (IO_WA_A8/~SPI_CS), U9.1 (~CS)
/config/SPI_IO0: U4.P2 (IO_WA_B7/SPI_D0), U9.5 (SI/SIO0)
/config/SPI_IO1: U4.P1 (IO_WA_A7/SPI_D1), U9.2 (SO/SIO1)
/config/SPI_IO2: R35.2, U4.R2 (IO_WA_B6/SPI_D2), U9.3 (~WP/SIO2)
/config/SPI_IO3: R33.2, U4.R1 (IO_WA_A6/SPI_D3), U9.7 (~RESET/SIO3)
/config/SPI_SCK: R37.1, U4.N4 (IO_WA_B8/SPI_CLK)
/config/~CFG_FAIL: U4.V2 (IO_WA_A2/~CFG_FAILED), U8.1 (1A)
/ethernet/ALED0: D9.1 (K), R59.1
/ethernet/ALED1: D10.1 (K), R63.1
/ethernet/ALED2: D11.1 (K), R64.1
/ethernet/ALED3: D12.1 (K), R65.1
/ethernet/ALED4: D13.1 (K), R86.1
/ethernet/ALED5: D14.1 (K), R87.1
/ethernet/ALED6: D15.1 (K), R88.1
/ethernet/ALED7: D16.1 (K), R95.1
/ethernet/BTN1: BTN1.2, R144.2, U4.C15 (IO_EB_B7)
/ethernet/BTN2: BTN2.2, R145.2, U4.A15 (IO_EB_B8)
/ethernet/BTN3: BTN3.2, R146.2, U4.B15 (IO_EB_A8)
/ethernet/FPD1+: J5.A6 (D+), J5.B6 (D+), R45.2
/ethernet/FPD1-: J5.A7 (D-), J5.B7 (D-), R44.2
/ethernet/LED0: D9.2 (A), U4.D15 (IO_EB_A7)
/ethernet/LED1: D10.2 (A), U4.C16 (IO_EB_B6)
/ethernet/LED2: D11.2 (A), U4.D16 (IO_EB_A6)
/ethernet/LED3: D12.2 (A), U4.A17 (IO_EB_B5)
/ethernet/LED4: D13.2 (A), U4.B17 (IO_EB_A5)
/ethernet/LED5: D14.2 (A), U4.C17 (IO_EB_B4)
/ethernet/LED6: D15.2 (A), U4.C18 (IO_EB_A4)
/ethernet/LED7: D16.2 (A), U4.E15 (IO_EB_B3)
/ethernet/USB25_N: R141.1, U4.L15 (IO_EA_B1), U4.M14 (IO_EA_B0)
/ethernet/USB25_P: R142.1, U4.L16 (IO_EA_A1), U4.M15 (IO_EA_A0)
/ethernet/USB_CC1: J5.A5 (CC1), R61.2
/ethernet/USB_CC2: J5.B5 (CC2), R62.2
/ethernet/USB_N: D4.1 (K), R44.1, R48.1, R55.2, R141.2
/ethernet/USB_P: D3.1 (K), R45.1, R46.2, R47.2, R58.1, R142.2
/ethernet/USB_PULL_N: D7.2 (A), D8.1 (K), U4.K17 (IO_EA_B2)
/ethernet/USB_PULL_P: D5.2 (A), D6.1 (K), U4.K18 (IO_EA_A2)
/lvds/+1V2_SA: C50.1, C51.1, C52.1, R121.2, U4.P6 (VDD_SA), U4.P8 (VDD_SA), U4.P10 (VDD_SA), U4.U6 (VDD_SA), U4.U9 (VDD_SA)
/lvds/+1V8_SB: C53.1, C54.1, C55.1, R122.1, U4.N11 (VDD_SB), U4.N13 (VDD_SB), U4.N18 (VDD_SB), U4.R15 (VDD_SB), U4.T18 (VDD_SB)
/lvds/CLK_25MHz: U4.N14 (CLK0/IO_SB_A8), Y1.3
/serdes/SER_CK_N: C137.1, R108.2, U4.T13 (SER_CLK_N), X2.5 (OUT-)
/serdes/SER_CK_P: C136.1, R108.1, U4.T12 (SER_CLK), X2.4 (OUT+)
/serdes/SER_PORT_ADJ: C133.1, R112.2, R113.1, U4.V15 (POR_ADJ)
GND: C1.2, C2.2, C4.1, C6.2, C8.2, C10.2, C11.2, C13.2, C14.2, C15.2, C16.2, C17.2, C18.2, C21.2, C22.2, C23.2, C24.2, C26.2, C27.2, C28.2, C29.2, C31.2, C32.2, C33.2, C34.2, C35.2, C36.2, C37.2, C38.2, C39.2, C40.2, C41.2, C42.2, C43.2, C44.2, C45.2, C47.2, C48.2, C49.2, C50.2, C51.2, C52.2, C53.2, C54.2, C55.2, C56.2, C57.2, C58.2, C75.2, C76.2, C77.2, C78.2, C79.2, C80.2, C85.2, C86.2, C87.2, C88.2, C89.2, C90.2, C91.2, C92.2, C93.2, C94.2, C95.2, C96.2, C97.2, C98.2, C99.2, C100.2, C101.2, C102.2, C103.2, C120.2, C121.2, C122.2, C123.2, C124.2, C125.2, C126.2, C127.2, C128.2, C131.2, C132.2, C133.2, C138.2, C140.2, C141.2, D1.1 (K), D2.1 (K), D3.2 (A), D4.2 (A), J3.2, J4.6, J5.GND, J5.S (SHIELD), J10.1 (GND), J10.3 (GND), J10.9 (GND), J10.15 (GND), J10.21 (GND), J10.27 (GND), J10.33 (GND), J10.39 (GND), J10.45 (GND), J10.51 (GND), J10.57 (GND), J10.71 (GND), J10.73 (GND), J10.75 (GND), J102.2, R2.2, R4.2, R7.2, R8.2, R12.1, R18.2, R24.2, R25.2, R27.2, R29.2, R30.2, R39.2, R59.2, R61.1, R62.1, R63.2, R64.2, R65.2, R86.2, R87.2, R88.2, R95.2, R109.1, R113.2, R118.2, TP7.1 (1_1), TP9.1 (1_1), TP11.1 (1_1), U1.2 (GND), U3.1 (AGND), U3.16 (PGND), U4.A1 (GND), U4.A7 (GND), U4.A10 (GND), U4.A13 (GND), U4.A18 (GND), U4.B16 (GND), U4.C1 (GND), U4.E5 (GND), U4.E7 (GND), U4.E9 (GND), U4.E11 (GND), U4.E13 (GND), U4.E18 (GND), U4.F1 (GND), U4.F6 (GND), U4.F8 (GND), U4.F10 (GND), U4.F12 (GND), U4.F14 (GND), U4.G5 (GND), U4.G7 (GND), U4.G9 (GND), U4.G11 (GND), U4.G13 (GND), U4.H6 (GND), U4.H8 (GND), U4.H10 (GND), U4.H12 (GND), U4.H14 (GND), U4.H18 (GND), U4.J1 (GND), U4.J5 (GND), U4.J7 (GND), U4.J9 (GND), U4.J11 (GND), U4.J13 (GND), U4.K6 (GND), U4.K8 (GND), U4.K10 (GND), U4.K12 (GND), U4.K14 (GND), U4.L5 (GND), U4.L7 (GND), U4.L9 (GND), U4.L11 (GND), U4.L13 (GND), U4.L18 (GND), U4.M1 (GND), U4.M6 (GND), U4.M8 (GND), U4.M10 (GND), U4.M12 (GND), U4.M16 (GND), U4.N7 (GND), U4.N9 (GND), U4.N12 (GND), U4.N17 (GND), U4.P4 (GND), U4.P7 (GND), U4.P9 (GND), U4.R12 (GND), U4.R16 (GND), U4.T4 (GND), U4.T11 (GND), U4.T17 (GND), U4.U14 (GND), U4.U15 (GND), U4.V1 (GND), U4.V6 (GND), U4.V9 (GND), U4.V14 (GND), U4.V18 (GND), U5.2 (GND), U6.3 (GND), U7.4 (GND), U8.4 (GND), U9.4 (GND), U10.A1 (VSS), U10.A3 (VSSQ), U10.B7 (VSSQ), U10.C3 (VSSQ), U10.D7 (VSSQ), U10.E3 (VSS), U10.J1 (VSS), X2.3 (GND), Y1.2
unnamed: BTN1.1, BTN2.1, BTN3.1, R118.1
unnamed: C6.1, C8.1, L1.2, R3.1, R10.1, TP1.1 (1_1)
unnamed: C24.1, C29.1, L3.2, R17.1, R21.1, TP4.1 (1_1)
unnamed: D1.2 (A), R31.2
unnamed: D2.2 (A), R32.2
unnamed: D5.1 (K), R46.1
unnamed: D6.2 (A), R47.1
unnamed: D7.1 (K), R48.2
unnamed: D8.2 (A), R55.1
unnamed: J3.1, R14.1
unnamed: J3.3, R16.1
unnamed: J4.1, J101.1, R40.2
unnamed: J4.2, J101.2, R41.2
unnamed: J4.3, J101.3, R42.2
unnamed: J4.4, J101.4, R43.2
unnamed: R7.1, U4.U16 (GND)
unnamed: R8.1, U4.V16 (GND)
unnamed: R3.2, R4.1, U1.5 (FB)
unnamed: L1.1, U1.3 (SW)
unnamed: R1.2, R2.1, U3.4 (EN)
unnamed: R12.2, R14.2, R15.2, R16.2, U3.2 (FB)
unnamed: C10.1, R13.1, R15.1, TP3.1 (1_1), U3.3 (OUT_S), U3.8 (OUT), U3.9 (OUT), U3.10 (OUT)
unnamed: U3.5 (SW), U3.6 (SW), U3.7 (SW), U3.15 (SW)
unnamed: R109.2, U4.V12 (SER_RTERM)
unnamed: TP12.1 (1_1), U4.R4 (IO_WA_B5/SPI_FWD)
unnamed: R9.1, U4.N16 (NC)
unnamed: R17.2, R18.1, U5.5 (FB)
unnamed: L3.1, U5.3 (SW)
unnamed: U6.4 (Y), U7.1 (1A)
unnamed: U7.2 (1B), U7.3 (2Y)
unnamed: R31.1, U7.5 (2A), U7.7 (1Y)
unnamed: U8.2 (1B), U8.3 (2Y)
unnamed: R32.1, U8.5 (2A), U8.7 (1Y)
unnamed: R37.2, U9.6 (SCLK)
unnamed: R143.2, X2.1 (OE)
RST_N: C138.1, R111.2, U4.N15 (IO_SB_B8), U4.T15 (RST_N), U7.6 (2B), U8.6 (2B)
SDRAM_A0: U4.D10 (IO_NB_A1), U10.H7 (A0)
SDRAM_A1: U4.D11 (IO_NB_A3), U10.H8 (A1)
SDRAM_A2: U4.C10 (IO_NB_B1), U10.J8 (A2)
SDRAM_A3: U4.A9 (IO_NB_B0), U10.J7 (A3)
SDRAM_A4: U4.C6 (IO_NA_A3), U10.J3 (A4)
SDRAM_A5: U4.D6 (IO_NA_B3), U10.J2 (A5)
SDRAM_A6: U4.A6 (IO_NA_A4), U10.H3 (A6)
SDRAM_A7: U4.D7 (IO_NA_B5), U10.H2 (A7)
SDRAM_A8: U4.C5 (IO_NA_B2), U10.H1 (A8)
SDRAM_A9: U4.C7 (IO_NA_A5), U10.G3 (A9)
SDRAM_A10: U4.B9 (IO_NB_A0), U10.H9 (A10)
SDRAM_A11: U4.B6 (IO_NA_B4), U10.G2 (A11)
SDRAM_A12: U4.B5 (IO_NA_A2), U10.G1 (A12)
SDRAM_BA0: U4.B8 (IO_NA_B7), U10.G7 (BA0)
SDRAM_BA1: U4.C9 (IO_NA_A8), U10.G8 (BA1)
SDRAM_CKE: U4.C8 (IO_NA_A6), U10.F3 (CKE)
SDRAM_CLK: U4.D8 (IO_NA_B6), U10.F2 (CLK)
SDRAM_D0: U4.C14 (IO_NB_B8), U10.A8 (DQ0)
SDRAM_D1: U4.C13 (IO_NB_B6), U10.B9 (DQ1)
SDRAM_D2: U4.D14 (IO_NB_A8), U10.B8 (DQ2)
SDRAM_D3: U4.B12 (IO_NB_A4), U10.C9 (DQ3)
SDRAM_D4: U4.D13 (IO_NB_A6), U10.C8 (DQ4)
SDRAM_D5: U4.B11 (IO_NB_A2), U10.D9 (DQ5)
SDRAM_D6: U4.A12 (IO_NB_B4), U10.D8 (DQ6)
SDRAM_D7: U4.C12 (IO_NB_B5), U10.E9 (DQ7)
SDRAM_D8: U4.B4 (IO_NA_B1), U10.E1 (DQ8)
SDRAM_D9: U4.A3 (IO_NA_A0), U10.D2 (DQ9)
SDRAM_D10: U4.B3 (IO_NA_B0), U10.D1 (DQ10)
SDRAM_D11: U4.C3 (IO_WC_A7), U10.C2 (DQ11)
SDRAM_D12: U4.C4 (IO_WC_B7), U10.C1 (DQ12)
SDRAM_D13: U4.B2 (IO_WC_B8), U10.B2 (DQ13)
SDRAM_D14: U4.B1 (IO_WC_A8), U10.B1 (DQ14)
SDRAM_D15: U4.D4 (IO_WC_B6), U10.A2 (DQ15)
SDRAM_DQM0: U4.A11 (IO_NB_B2), U10.E8 (DQML)
SDRAM_DQM1: U4.A4 (IO_NA_A1), U10.F1 (DQMH)
SDRAM_VCC: C57.1, C58.1, C75.1, C76.1, C77.1, C78.1, C79.1, C80.1, C86.1, C87.1, C88.1, C89.1, C90.1, C91.1, C92.1, C93.1, R115.1, R116.1, U4.A2 (VDD_WC), U4.A5 (VDD_NA), U4.B7 (VDD_NA), U4.B10 (VDD_NB), U4.B13 (VDD_NB), U4.C2 (VDD_WC), U4.D5 (VDD_WC), U4.E6 (VDD_NA), U4.E8 (VDD_NA), U4.E10 (VDD_NB), U4.E12 (VDD_NB), U4.F2 (VDD_WC), U4.F5 (VDD_WC), U4.F7 (VDD_NA), U4.F11 (VDD_NB), U4.H5 (VDD_WB), U4.J2 (VDD_WB), U4.K5 (VDD_WB), U4.M2 (VDD_WB), U4.M5 (VDD_WB), U10.A7 (VDDQ), U10.A9 (VDD), U10.B3 (VDDQ), U10.C7 (VDDQ), U10.D3 (VDDQ), U10.E7 (VDD), U10.J9 (VDD)
SDRAM_nCAS: U4.D9 (IO_NA_B8), U10.F7 (~CAS)
SDRAM_nCS: U4.C11 (IO_NB_B3), U10.G9 (~CS)
SDRAM_nRAS: U4.A8 (IO_NA_A7), U10.F8 (~RAS)
SDRAM_nWE: U4.D12 (IO_NB_A5), U10.F9 (~WE)
VDD_CLK: C4.2, C47.1, C48.1, C56.1, C126.1, C131.1, C132.1, J4.5, R10.2, R33.1, R34.1, R35.1, R36.1, R38.1, R66.1, R111.1, R112.1, R116.2, R122.2, R123.2, R143.1, R144.1, R145.1, R146.1, SW1.1, SW1.2, U4.T14 (VDD_CLK), U6.6 (VCC), U7.8 (VCC), U8.8 (VCC), U9.8 (VCC), X2.6 (VDD), Y1.1, Y1.4
VDD_CORE: C13.1, C14.1, C15.1, C16.1, C17.1, C18.1, C21.1, C22.1, C23.1, C26.1, C27.1, C28.1, C31.1, C32.1, C33.1, C34.1, C35.1, C36.1, C37.1, C38.1, C39.1, C40.1, C41.1, C120.1, C121.1, C122.1, C123.1, C124.1, C125.1, R13.2, R23.1, R105.1, R106.1, U4.F9 (VDD), U4.G6 (VDD), U4.G8 (VDD), U4.G10 (VDD), U4.G12 (VDD), U4.H7 (VDD), U4.H9 (VDD), U4.H11 (VDD), U4.H13 (VDD), U4.J6 (VDD), U4.J8 (VDD), U4.J10 (VDD), U4.J12 (VDD), U4.K7 (VDD), U4.K9 (VDD), U4.K11 (VDD), U4.K13 (VDD), U4.L6 (VDD), U4.L8 (VDD), U4.L10 (VDD), U4.L12 (VDD), U4.M7 (VDD), U4.M9 (VDD), U4.M11 (VDD), U4.M13 (VDD), U4.N6 (VDD), U4.N8 (VDD), U4.N10 (VDD)
VDD_PLL: C42.1, R23.2, TP6.1 (1_1), U4.P16 (VDD_PLL)
VDD_SER: C128.1, R9.2, R106.2, TP10.1 (1_1), U4.U12 (VDD_SER), U4.V17 (VDD_SER)
VDD_SER_PLL: C127.1, R105.2, TP8.1 (1_1), U4.T16 (VDD_SER_PLL)

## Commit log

2026-04-13 Adding M2
    [cm4-gpio.kicad_sch, cm4-hsio.kicad_sch, config.kicad_sch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]
2026-06-03 Version 1.0
    [config.kicad_sch, ethernet.kicad_sch, gpio.kicad_sch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]
2026-06-03 Cleanup for v2 - we need to remove all modules, rotate FPGA, then assemble them together
    [ulx5m-m2.kicad_pcb]
2026-06-03 Chaning place of SDRAM
    [cm4-gpio.kicad_sch, cm4-hsio.kicad_sch, config.kicad_sch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]
2026-10-08 Switching to 6L board - routing - adding schemaitcs
    [config.kicad_sch, ethernet.kicad_sch, gpio.kicad_sch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]
2026-10-29 moving capacitor so when uscilator is used they can be removed

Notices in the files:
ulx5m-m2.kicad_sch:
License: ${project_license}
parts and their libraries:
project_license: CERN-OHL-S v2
